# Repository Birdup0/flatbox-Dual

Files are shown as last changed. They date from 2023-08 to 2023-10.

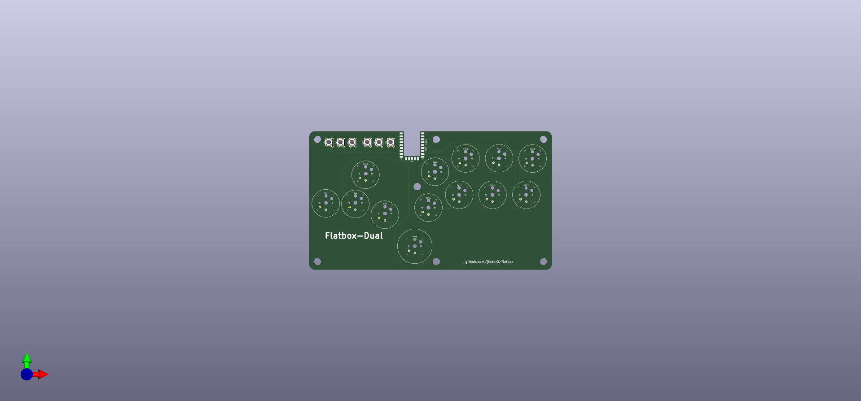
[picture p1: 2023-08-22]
Flatbox-Dual/Flatbox-Dual(V1 only)/Flatbox-Dual.png

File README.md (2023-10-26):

# Flatbox-Dual: Low profile hitbox-layout fightstick
Flatbox-Dual


This is a fork of the flatbox-rev5 with a extra button that can be bound to either jump or another buttons through GP2040CE web configuration.

it fits both V1 and V2 choc low profile switches with hot-swap sockets.

The building process is almost 1:1 as with the flatbox rev5 with only needing one more hotswap socket and switch.

# Special thanks to
Jfedor 

The GP2040CE team

and the people at the open stick discord for all the insight and help which made this possible.

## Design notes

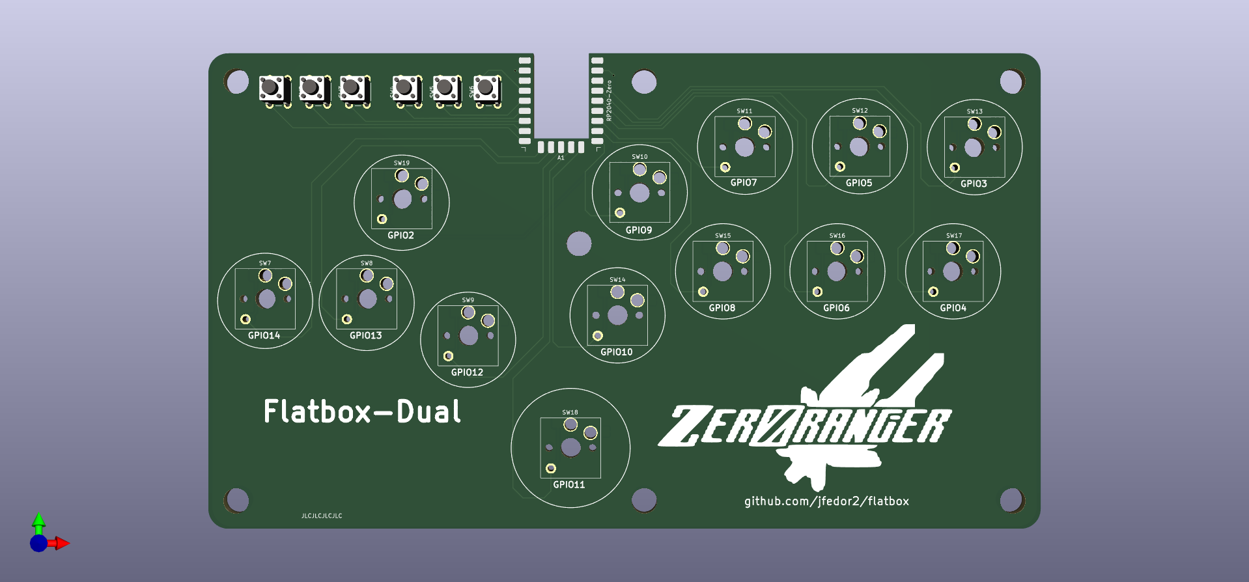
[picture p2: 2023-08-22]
Flatbox-Dual/Flatbox-Dual.png

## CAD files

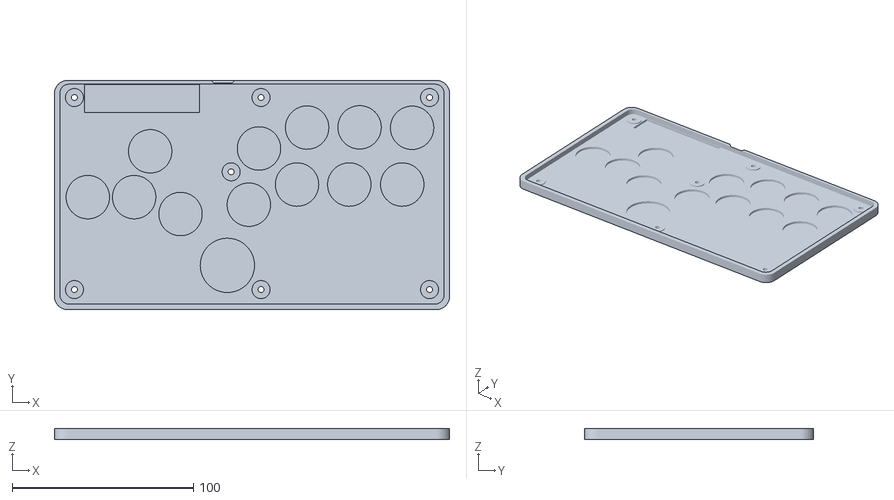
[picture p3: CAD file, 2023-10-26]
Flatbox-Dual/Case/Bottom panel.stl
218.0 x 126.4 x 6.20

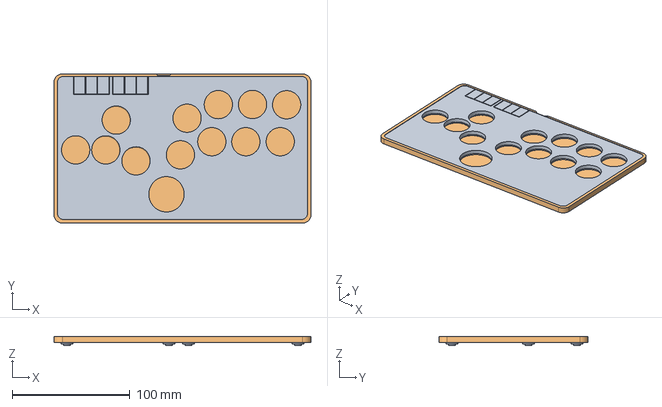
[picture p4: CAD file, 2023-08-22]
Flatbox-Dual/Flatbox-Dual(V1 only)/Step files/Flatbox-Dual1.1-Case.step
218.0 x 126.4 x 7.60 mm

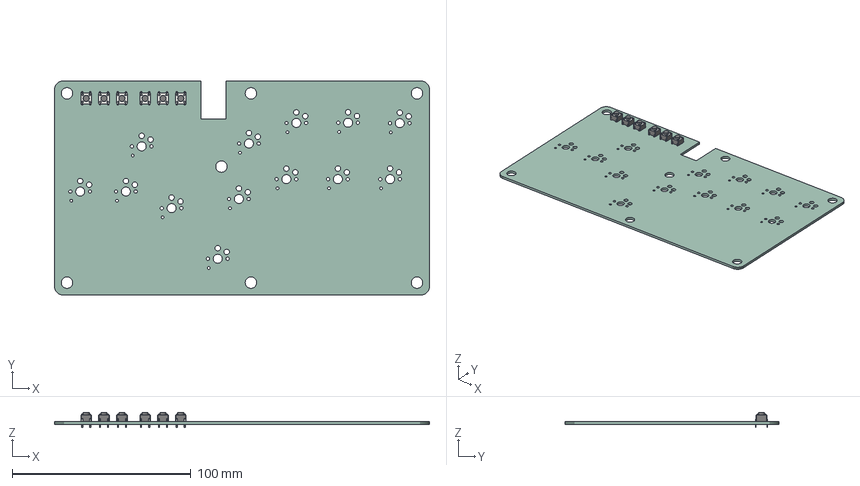
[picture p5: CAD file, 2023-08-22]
Flatbox-Dual/Step files/Flatbox-Dual-PCB.step
210.0 x 120.0 x 8.50 mm
PCB

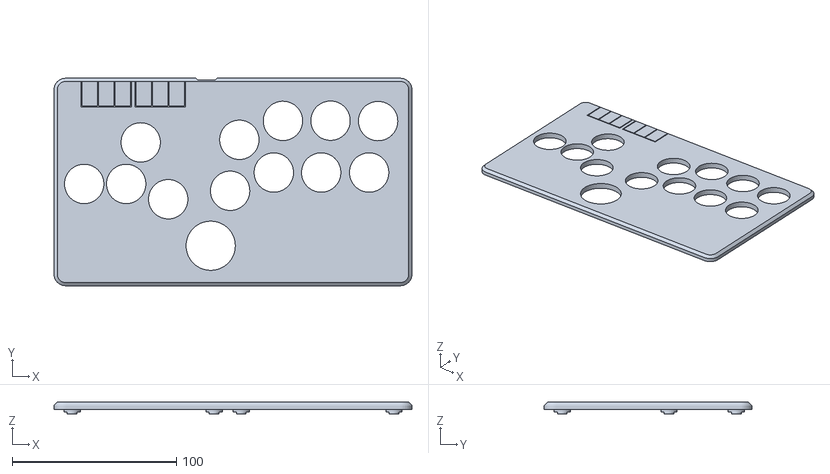
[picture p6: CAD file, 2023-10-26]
Flatbox-Dual/Case/Top panel.stl
218.0 x 126.4 x 7.20

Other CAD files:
Flatbox-Dual/Flatbox-Dual(V1 only)/Step files/Flatbox-Dual-pcb.step

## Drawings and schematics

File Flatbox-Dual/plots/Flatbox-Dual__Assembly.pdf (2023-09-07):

JLCJLCJLCJLC | RP²⁰⁴⁰⁻Zero GPIO2 | GPIO7 | GPIO5 | GPIO4 GPIO14 | github.com/jfedor2/flatbox GPIO11 | GPIO8 | GPIO3 GPIO6 GPIO10 Flatbox-Dual | GPIO9 GPIO12 GPIO13

A

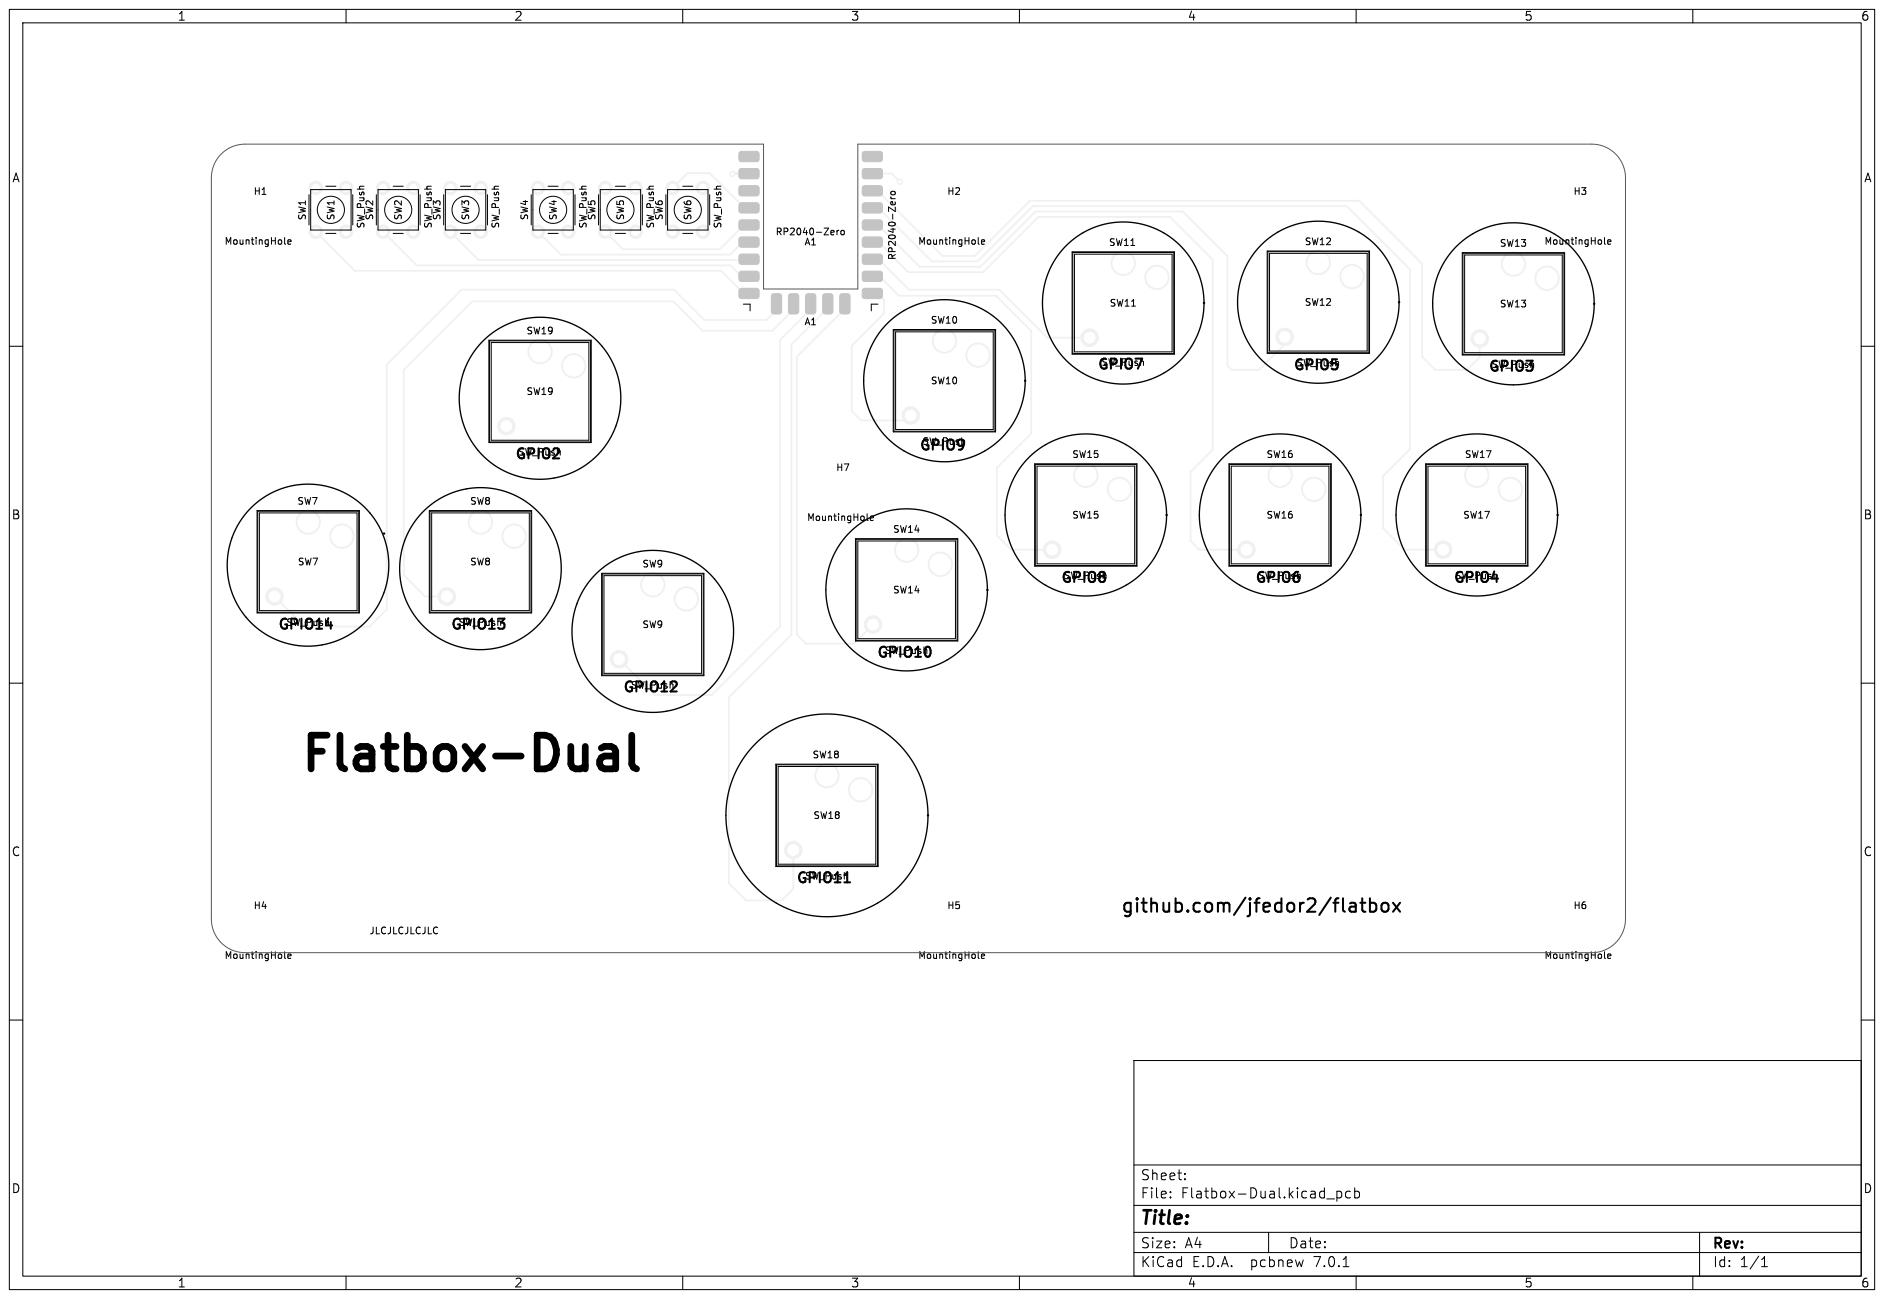
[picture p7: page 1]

1 | 2 | 3 | 4 | 5 | 6

A

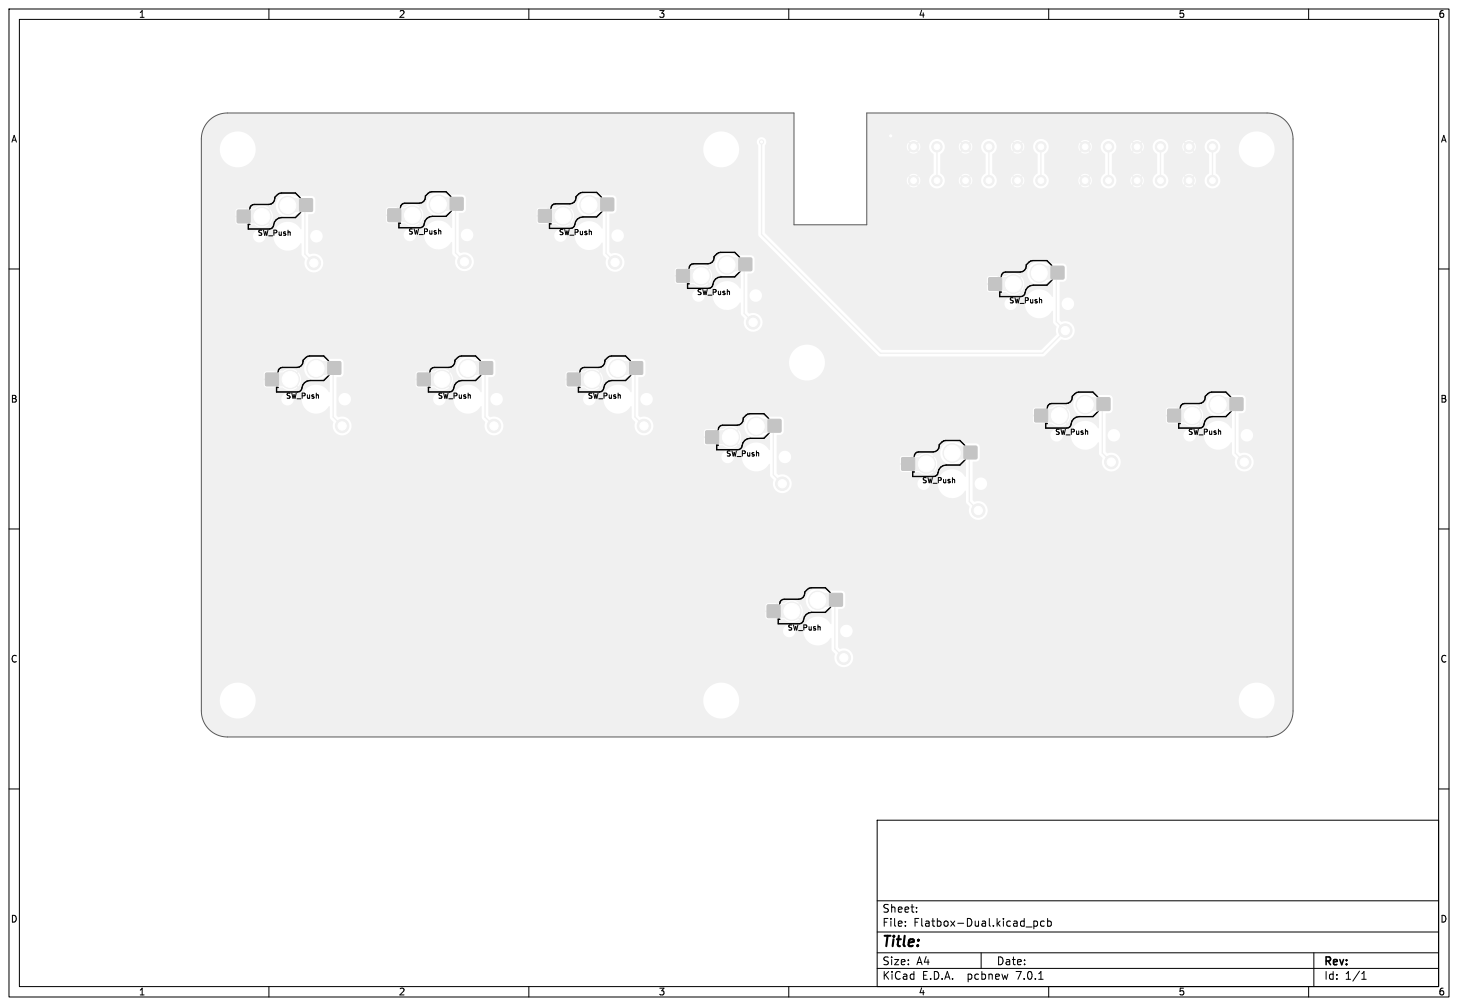
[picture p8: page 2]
D Date: KiCad; pcbnew 7.0.1 Size: A4; Rev:; Id: 1/1 Title: File:; Flatbox-Dual.kicad_pcb Sheet:

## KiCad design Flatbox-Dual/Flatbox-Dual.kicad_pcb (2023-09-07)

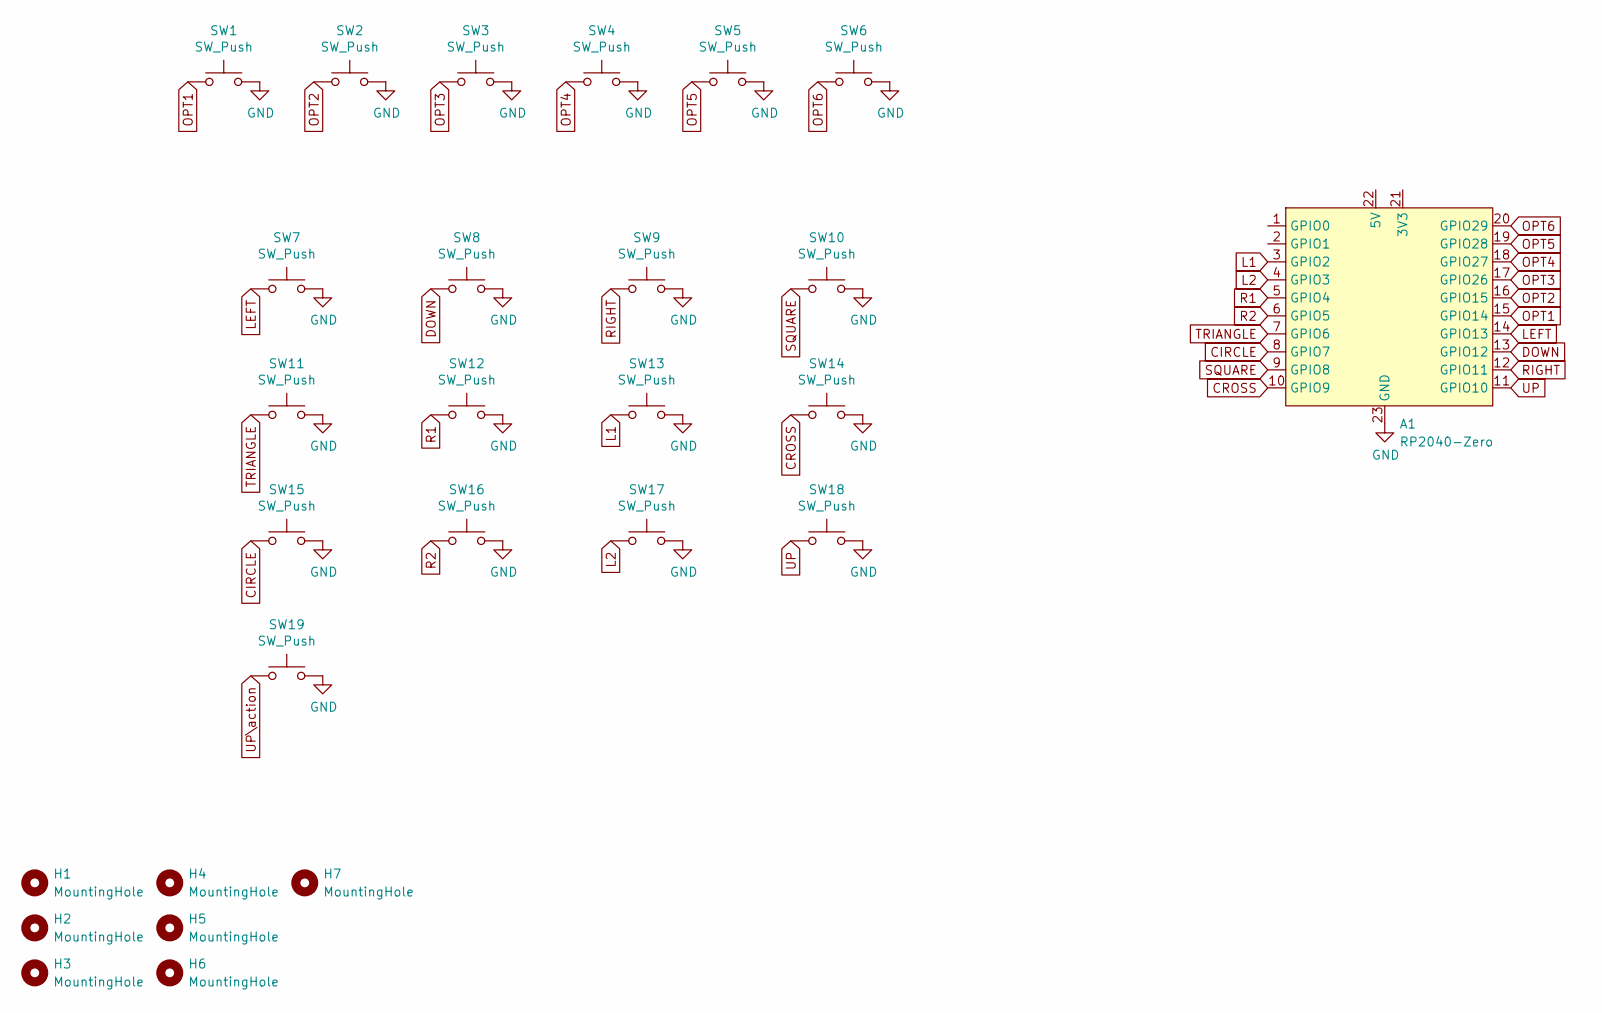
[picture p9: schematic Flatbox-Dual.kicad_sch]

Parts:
A1: RP2040-Zero
H1, H2, H3, H4, H5, H6, H7: MountingHole; MountingHole_6.4mm_M6
SW1, SW2, SW3, SW4, SW5, SW6: SW_Push; SW_PUSH_6mm_H5mm
SW7, SW8, SW9, SW10, SW11, SW12, SW13, SW14, SW15, SW16, SW17, SW18, SW19: SW_Push; Kailh_socket_PG1350_optional

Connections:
CIRCLE: A1.8 (GPIO7), SW15.1
CROSS: A1.10 (GPIO9), SW14.1
DOWN: A1.13 (GPIO12), SW8.1
GND: A1.23 (GND), SW1.2, SW2.2, SW3.2, SW4.2, SW5.2, SW6.2, SW7.2, SW8.2, SW9.2, SW10.2, SW11.2, SW12.2, SW13.2, SW14.2, SW15.2, SW16.2, SW17.2, SW18.2, SW19.2
L1: A1.3 (GPIO2), SW13.1
L2: A1.4 (GPIO3), SW17.1
LEFT: A1.14 (GPIO13), SW7.1
OPT1: A1.15 (GPIO14), SW1.1
OPT2: A1.16 (GPIO15), SW2.1
OPT3: A1.17 (GPIO26), SW3.1
OPT4: A1.18 (GPIO27), SW4.1
OPT5: A1.19 (GPIO28), SW5.1
OPT6: A1.20 (GPIO29), SW6.1
R1: A1.5 (GPIO4), SW12.1
R2: A1.6 (GPIO5), SW16.1
RIGHT: A1.12 (GPIO11), SW9.1
SQUARE: A1.9 (GPIO8), SW10.1
TRIANGLE: A1.7 (GPIO6), SW11.1
UP: A1.11 (GPIO10), SW18.1
UP\action: A1.2 (GPIO1), SW19.1

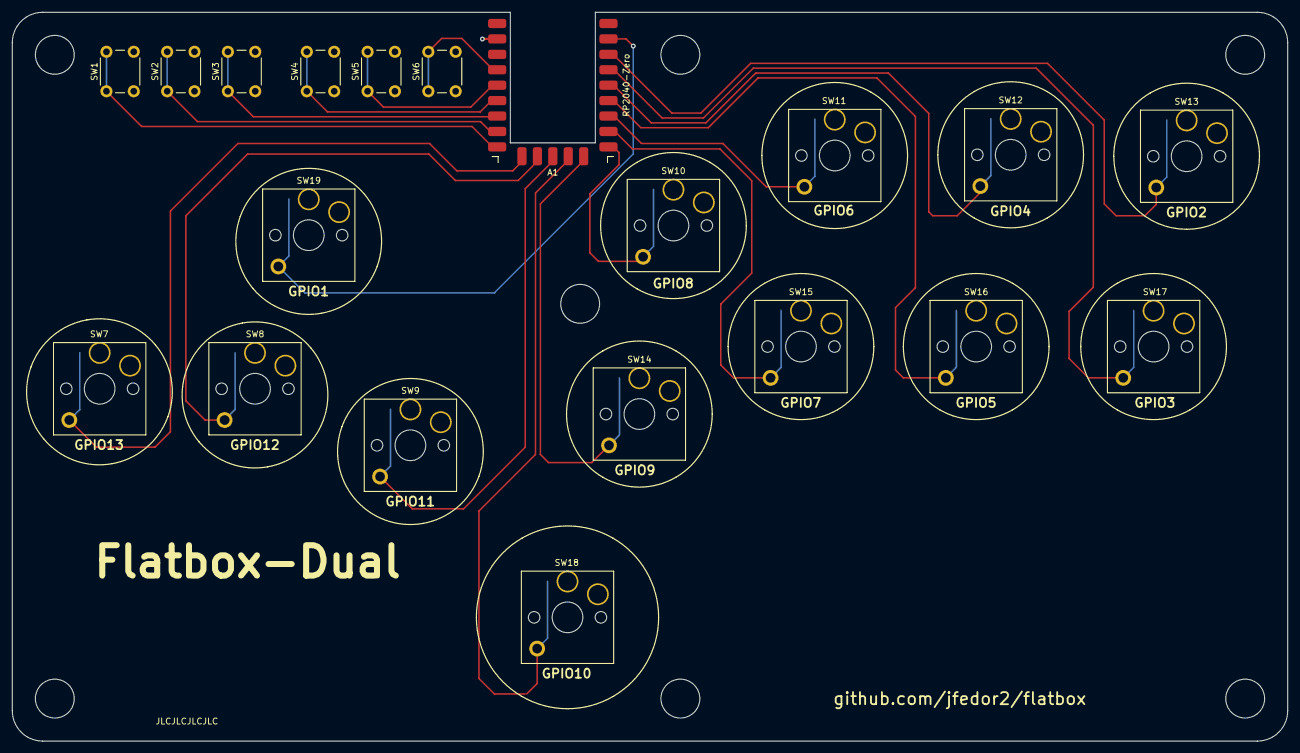
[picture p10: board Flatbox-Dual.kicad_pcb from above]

Board: 2 copper layers, 210.0 x 120.0 mm, 27 parts (0 on the bottom side), 20 nets.

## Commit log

2023-09-07 Add files via upload
    Fixed an issue with the GPIO labels.
    [Bottom panel.stl, Flatbox-Dual v1v2.kicad_pcb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]
2023-10-26 Updating the case stls
    [Bottom panel.stl, Top panel.stl]
2023-10-26 case Stl updated
    [Bottom panel.stl, Top panel.stl]
